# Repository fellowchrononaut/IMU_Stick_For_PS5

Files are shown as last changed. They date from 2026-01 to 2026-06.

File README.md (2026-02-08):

Idea is to create a peripheral for PS5 Access Controller that would allow single joystick control using orientation sensor.

Prototype Circuit :

Note:
There are 2 output TRRS connectors
1. Output directly from Voltage Divider might drop with the 1.8v PS5 Access Controller Vdd load
2. Output from op-amp (LM358P) should theoretically maintain voltage even with the PS5 Access Controller Load (1.8v Vdd)

Limitations:
- Output can only reach a maximum of 1.65v for each channel because I did not have the right combination of resistors for the voltage divider. This means that we lose some range as the controller accepts upto 1.8v.
- Because of the follower circuit of the op-amp, the voltage changes may not be responsive enough.

TODO:

- Test on the PS5 Access controller
- Try voltage divider with 10k+12k resistors instead of the current 10k+10k
- Use the Digipot for smoother control
- Design casing and strap for placement on foot

<p align='center'>
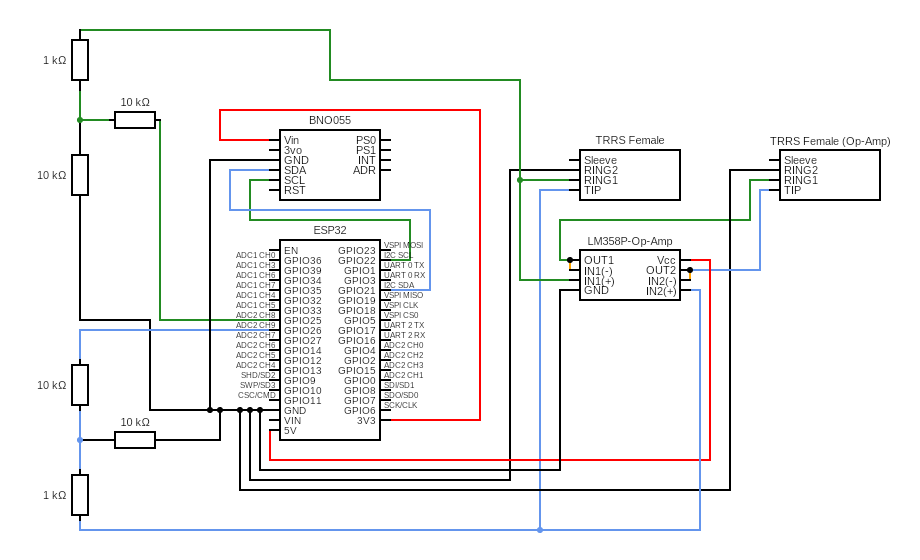
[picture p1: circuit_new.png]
    
</p>

<p align='center'>
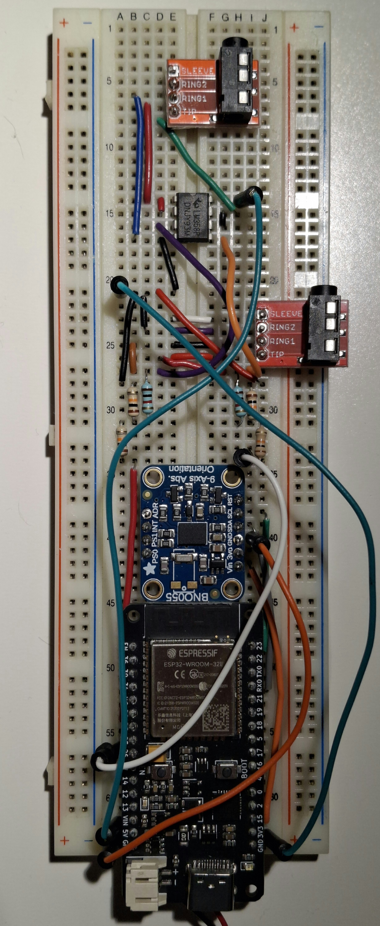
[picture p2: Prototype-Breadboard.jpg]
    
</p>

<p align='center'>
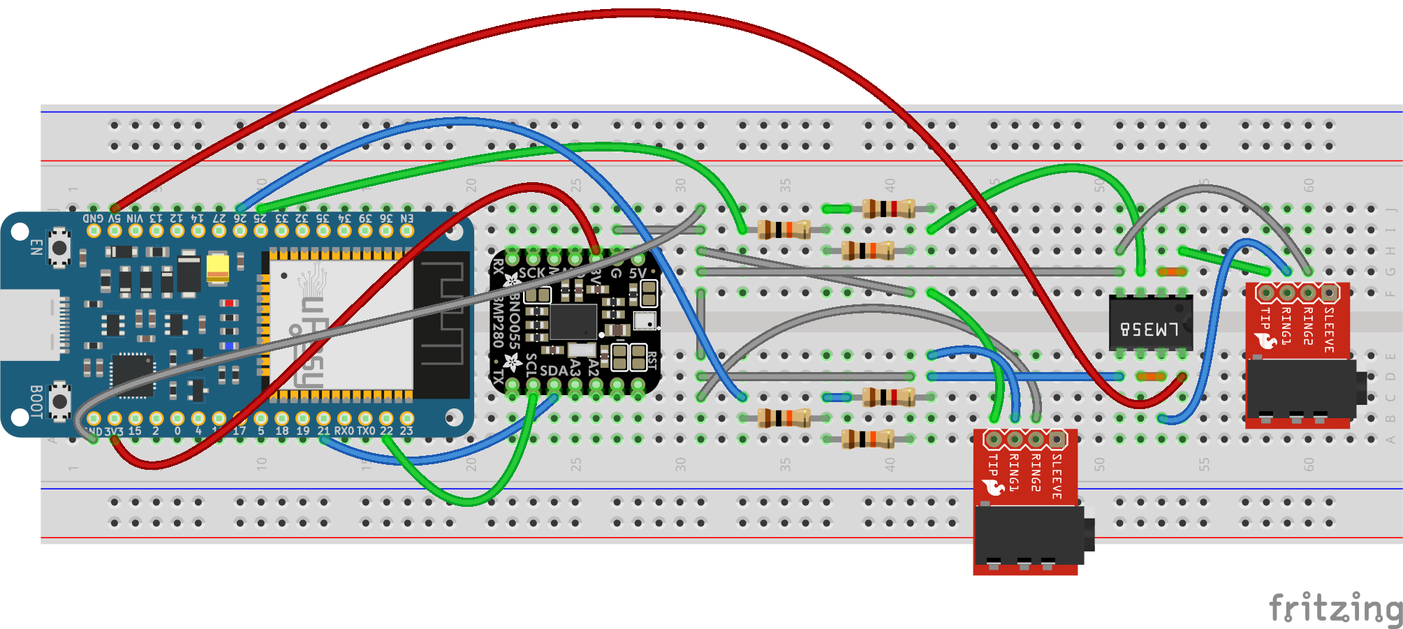
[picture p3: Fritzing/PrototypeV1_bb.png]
    
</p>

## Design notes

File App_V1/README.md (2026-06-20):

# IMU Stick V1 — App + Firmware

Desktop configurator and ESP32 firmware for the foot-mounted IMU → PS5 Access
Controller stick adapter.

- `firmware/imu_stick_v1/` — Arduino sketch for the ESP32 (BNO055 + DAC out)
- `app/imu_stick_app.py` — Tkinter desktop configurator
- `requirements.txt` — Python dependencies

---

## Quick start (desktop side)

Tested on Ubuntu / Python 3.10+. Should work on any Python 3.8+ system with
Tkinter available.

```bash
cd App_V1
python3 -m venv .venv
source .venv/bin/activate
pip install -r requirements.txt
python app/imu_stick_app.py
```

On Windows or macOS, the virtual gamepad panel will be unavailable (evdev is
Linux-only) but everything else works.

---

## Linux system permissions

Two permissions to set up once. Both persist across reboots.

### Serial port access (so the app can read `/dev/ttyUSB0` without sudo)

```bash
sudo usermod -aG dialout $USER
# log out and back in for group membership to take effect
```

### Virtual gamepad access to `/dev/uinput` (only if you want that feature)

```bash
sudo groupadd -f uinput
sudo usermod -aG uinput,input $USER
echo 'KERNEL=="uinput", MODE="0660", GROUP="uinput", OPTIONS+="static_node=uinput"' \
    | sudo tee /etc/udev/rules.d/99-uinput.rules
sudo udevadm control --reload-rules && sudo udevadm trigger
# log out and back in
```

If you skip this step, the "Enable virtual gamepad output" checkbox will fail
with a permission error in the status line — harmless, just disabled.

---

## Firmware setup

Arduino IDE 2.x. Once-per-machine setup:

1. **ESP32 board package**:
   - `File → Preferences → Additional boards manager URLs`:
     `https://raw.githubusercontent.com/espressif/arduino-esp32/gh-pages/package_esp32_index.json`
   - `Tools → Board → Boards Manager…` → install **esp32 by Espressif Systems**.

2. **BNO055 library** (the Bosch one, not Adafruit's):
   - The project lives at the same path used by the V0 sketch:
     `~/Arduino/libraries/BNO055/`. If you don't have it, install Bosch's BNO055
     example sources there. Either copy from a working machine or use Renzo
     Mischianti's port which the V0 sketch is based on.

3. **Verify the I2C address** in `~/Arduino/libraries/BNO055/BNO055.h` is set to
   `BNO055_I2C_ADDR1` (0x28). This is the default; only change if your board is
   jumpered for 0x29.

4. Open `firmware/imu_stick_v1/imu_stick_v1.ino`, select the board (e.g.
   "ESP32 Dev Module"), select the port (`/dev/ttyUSB0` on Linux), and upload.

The very first line on the serial output after upload should be
`READY imu_stick_v1` — that confirms V1 firmware is running.

---

## Workflow

1. Plug ESP32 into the PC via USB.
2. Launch `python app/imu_stick_app.py`. It auto-connects to `/dev/ttyUSB0`.
3. (One-time, per chip) Wave the IMU until the calibration line reads
   `3, 3, 3, 3`, then click **Save chip cal to NVS** under "BNO055 sensor
   calibration". Future boots will skip the cal dance.
4. Hold the foot in the desired neutral pose and click **Set Neutral
   (capture pose)**.
5. Use the X/Y axis dropdowns, "Invert" checkboxes, and Max-angle / Deadzone
   spinboxes to dial in the mapping. Changes apply live so you can watch the
   DAC react in the readout / on the 2D stick / on the 3D pose viz.
6. Click **Save to ESP32 (persist)** to write the current settings to the
   active profile in NVS.
7. Unplug USB, plug into battery + PS5 controller. ESP32 boots and runs with
   the saved profile.

### Profiles

Use the dropdown to switch between saved profiles. "New…" prompts for a name
and saves current settings under it. "Delete" removes the selected profile
(except the active one — switch first, then delete).

Profile names: 1–12 chars, letters / digits / `_` / `-`.

---

## Troubleshooting

| Symptom | Likely cause |
|---|---|
| App opens but nothing populates | Port wrong, or firmware not the V1 build. The boot banner `READY imu_stick_v1` confirms V1 is running. |
| Live values stuck at all zeros | BNO055 not responding on I2C. Re-run `i2c_scanner` from the V0 folder to check. |
| `cal=0,...` and not climbing | BNO055 needs motion through several orientations. Gyro / accel / mag each calibrate via different motions; see Bosch datasheet section on calibration. |
| `DAC X/Y` won't budge | Baseline not yet captured — click **Set Neutral**. |
| Virtual gamepad checkbox shows "Permission denied" | uinput udev rule not yet applied; see Linux permissions section above. |
| 3D viz panel says "matplotlib not installed" | `pip install matplotlib numpy` in your venv. |

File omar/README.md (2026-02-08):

# README

### Objective

To develop a script and the hardware necessary to test the link between a microcontroller and the PS5 expansion ports.

### Parts List

- [Knockoff Waveshare RP2040-Zero](https://fr.aliexpress.com/item/1005007650325892.html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)
- [MCP4251-103E/P 8bit, dual SPI digital potentiometer with volatile memory](https://fr.farnell.com/en-FR/microchip/mcp4251-103e-p/ic-dpot-5-5v-10kr-14-pdip-spi/dp/1578442)
- [3.5mm Male To 3.5 mm Male TRRS Aux Cable](https://fr.aliexpress.com/item/1005009181119614.html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)
- [3.5mm Female Jack to Bare Wire Open End TRRS](https://fr.aliexpress.com/item/1005008510930978.html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)
- [USB-A to USB-C Cable](https://fr.aliexpress.com/item/1005008494569058.html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)
- [Starter Kit For Arduino](https://fr.aliexpress.com/item/1005006480276775.html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)
- [PS5 Access Controller](https://direct.playstation.com/fr-fr/buy-accessories/access-controller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:)
- [PS5](https://direct.playstation.com/fr-fr/buy-consoles/certified-refurbished-playstation5-digital-edition-console)

Total Cost (Excluding PS5 & Controller) : 40 euros

### Useful Resources

- [Waveshare RP2040-Zero Pinout](https://www.waveshare.com/rp2040-zero.htm)
- [How to configure Waveshare RP2040-Zero in Arduino IDE](https://www.waveshare.com/wiki/RP2040-Zero)
- [How to create a joystick input for PS5 access controller](https://www.youtube.com/watch?v=6_bBL7czNOw)
- [Digital potentiometers and Arduino](https://www.youtube.com/watch?v=AqeGskH0usY&t=781s)
- [Waveshare RP2040-Zero Fritzing component](https://forum.fritzing.org/t/part-request-waveshare-rp2040-zero/16705)
- [How to download Fritzing for free](https://gist.github.com/RyanLua/fc2457d87641bb39754278b01a647526)
- [SPI wikipedia overview](https://en.wikipedia.org/wiki/Serial_Peripheral_Interface#See_also)
- Access™ Controller for PlayStation®5 Expansion Port Specifications PDF
- Microchip MCP413X/415X/423X/425X Datasheet PDF

### Wiring

MCP4251 Pin Allocation

| MCP4251 Pin | Label | Connection Point | Description |
| :--- | :--- | :--- | :--- |
| **1** | CS | **GP5 (SPI CS)** | SPI Chip Select |
| **2** | SCK | **GP2 (SPI SCK)** | SPI Clock |
| **3** | SDI | **GP3 (SPI TX)** | SPI Data Input |
| **4** | Vss | **GND** | Common Ground |
| **5** | P1B | **GND** | Pot 1 Low Side (GND) |
| **6** | P1W | **TIP (Y-AXIS) + GP26 (ADC)** | Pot 1 Wiper |
| **7** | P1A | **Sleeve (1.8V Ref)** | Pot 1 High Side |
| **8** | P0A | **Sleeve (1.8V Ref)** | Pot 0 High Side |
| **9** | P0W | **RING 1 (X-AXIS) + GP27 (ADC)** | Pot 0 Wiper |
| **10** | P0B | **GND** | Pot 0 Low Side (GND) |
| **11** | WP | **3.3V** | Write Protect (Disabled) |
| **12** | SHDN | **3.3V** | Shutdown (Disabled) |
| **13** | SDO | N/A | Not Used |
| **14** | Vdd | **3.3V** | Chip Logic Power |

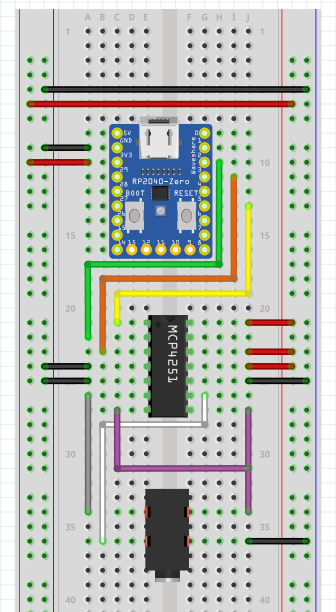
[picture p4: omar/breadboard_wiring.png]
Wiring


### Code Walkthrough

This program allows the user to send X/Y joystick commands to the PS5 Access Controller by modifying the wiper positions of the corresponding potentiometers via the serial port.

```cpp
#include <SPI.h>

const int CS_PIN = 5;
const byte POT_LEFT  = 0x10; // Wiper 1 (Left/Y-axis)
const byte POT_RIGHT = 0x00; // Wiper 0 (Right/X-axis)

const int ADC_LEFT  = 26;    // Monitor for wiper 1 (left/Y-axis)
const int ADC_RIGHT = 27;    // Monitor for wiper 0 (right/X-axis)

void setup() {

  Serial.begin(115200);
  
  // Specify which SPI pins used on RP2040
  SPI.setSCK(2);
  SPI.setTX(3);
  SPI.setRX(4);
  SPI.begin();

  // Set chip select pin to high at the start
  pinMode(CS_PIN, OUTPUT);
  digitalWrite(CS_PIN, HIGH);
  
  // 12 bit ADC on rp2040
  analogReadResolution(12);

  // Blahblah in serial port
  Serial.println("--- Dual-Channel PS5 Controller Tester ---");
  Serial.println("Commands: 'L' or 'R' followed by 0-255 (e.g., L128)");
  Serial.println("Type 'C' to Center both pots.");
  Serial.println("------------------------------------------");
}

void setWiper(byte address, int value) {

  // Failsafe to restrict wiper value commands
  value = constrain(value, 0, 255);

  // Send wiper value to digipot 
  SPI.beginTransaction(SPISettings(1000000, MSBFIRST, SPI_MODE0));
  digitalWrite(CS_PIN, LOW);
  SPI.transfer(address);
  SPI.transfer((byte)value);
  digitalWrite(CS_PIN, HIGH);
  SPI.endTransaction();
}

void displayVoltages() {

  // Read and store measured ADC values as voltages
  float vLeft = (analogRead(ADC_LEFT) * 3.3) / 4095.0;
  float vRight = (analogRead(ADC_RIGHT) * 3.3) / 4095.0;
  
  // Print measured voltages
  Serial.print(">> VOLTAGES | Left (GP26): ");
  Serial.print(vLeft, 3);
  Serial.print("V | Right (GP27): ");
  Serial.print(vRight, 3);
  Serial.println("V");
}

void loop() {

  // If buffer is not emtpy, interpret commands
  if (Serial.available() > 0) {
    char cmd = Serial.read();
    
    // If C/c, center both wipers
    if (cmd == 'C' || cmd == 'c') {
      Serial.println("Centering both sticks...");
      setWiper(POT_LEFT, 128);
      setWiper(POT_RIGHT, 128);
    } 
    else if (cmd == 'L' || cmd == 'l' || cmd == 'R' || cmd == 'r') {
      int val = Serial.parseInt();
      byte addr = (cmd == 'L' || cmd == 'l') ? POT_LEFT : POT_RIGHT;
      setWiper(addr, val);
      Serial.print("Set "); Serial.print(cmd); Serial.print(" to "); Serial.println(val);
    }

    // Clear buffer
    while(Serial.available() > 0) Serial.read(); 
    
    // Show results of the move
    delay(10); // Small delay for ADC stabilization
    displayVoltages();
  }
}
```

### Test Procedure

1. Turn ON PS5 Access Controller
2. Connect 3.5 mm Male jack to PS5 Access Controller expansion port
3. Verify voltage drop between the sleeve and ring 2 is 1.8V
4. Turn OFF PS5 Access Controller
5. Wire 3.5 mm jack to breadboard according to wiring diagram
6. Turn ON microcontroller and PS5 Access Controller
7. Send X/Y joystick commands from Arduino IDE serial port to PS5 Access Controller

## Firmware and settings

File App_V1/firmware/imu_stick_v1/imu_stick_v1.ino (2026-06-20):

/**
 * IMU Stick V1 firmware
 * - BNO055 over I2C (address 0x28, NDOF mode)
 * - Two ESP32 DAC channels driving a PS5 Access Controller stick via op-amp
 * - Configurable axis mapping (source, invert, max angle, deadzone) per channel
 * - Neutral pose calibration
 * - Multiple named profiles persisted in NVS
 * - BNO055 sensor calibration offsets persisted in NVS (skip re-cal on boot)
 *
 * Serial protocol (line-based, 115200 baud):
 *   Host -> ESP32:
 *     STATUS                              dump current config (CFG line)
 *     SET X.src=heading Y.inv=1 ...       update any subset of X/Y fields in RAM
 *     NEUTRAL                             capture current pose as baseline (RAM)
 *     SAVE                                persist current RAM config to active profile
 *     LOAD                                reload active profile from NVS into RAM
 *     RESET                               restore defaults in RAM (Save to persist)
 *     LIST_PROFILES                       reply: PROFILES <comma list>
 *     SELECT_PROFILE <name>               load profile into RAM, set active
 *     SAVE_PROFILE <name>                 save RAM config as <name>, mark active
 *     DELETE_PROFILE <name>               remove named profile
 *     SAVE_BNO_CAL                        snapshot BNO055 cal offsets to NVS
 *     CLEAR_BNO_CAL                       remove saved BNO055 cal
 *   ESP32 -> host:
 *     READY imu_stick_v1                  on boot
 *     CFG ...                             reply to STATUS; includes profile=, bno_cal_saved=
 *     PROFILES <name1,name2,...>          reply to LIST_PROFILES (empty -> "PROFILES")
 *     OK ... / ERR ...                    command replies
 *     D h=.. p=.. r=.. dx=.. dy=.. cal=s,g,a,m baseline_set=0|1
 *                                         streamed at ~10 Hz
 *
 * NVS keys (namespace "imuv1"):
 *   active        active profile name (string, default "default")
 *   prof_list     comma-separated profile names
 *   p_<name>      Config blob (per profile)
 *   bno_cal       22-byte BNO055 calibration offset blob
 */

#include "BNO055_support.h"
#include <Wire.h>
#include <Preferences.h>

#define DAC_X 25                    // Ring 1 on TRRS (stick X)
#define DAC_Y 26                    // Tip on TRRS (stick Y)
#define BNO055_SAMPLERATE_DELAY_MS 100
#define CONFIG_MAGIC 0xC0DE
#define BNO055_I2C_ADDRESS 0x28
#define BNO055_CAL_REG_START 0x55
#define BNO055_CAL_BLOB_SIZE 22
#define PROFILE_NAME_MAX 12

enum AxisSource : uint8_t { SRC_HEADING = 0, SRC_PITCH = 1, SRC_ROLL = 2 };

struct AxisConfig {
  uint8_t src;
  uint8_t invert;
  float max_angle;
  float dead_zone;
};

struct Config {
  AxisConfig x;
  AxisConfig y;
  float baseline_heading;
  float baseline_pitch;
  float baseline_roll;
  uint8_t baseline_set;
  uint16_t magic;
};

Config cfg;
char activeProfile[PROFILE_NAME_MAX + 1] = "default";
bool bnoCalSaved = false;

struct bno055_t myBNO;
struct bno055_euler myEulerData;
unsigned char sysCal = 0, gyroCal = 0, accelCal = 0, magCal = 0;

unsigned long lastSample = 0;
String inputLine;
Preferences prefs;

// ---------------- defaults ----------------
void loadDefaults() {
  cfg.x = { SRC_HEADING, 0, 25.0f, 0.0f };
  cfg.y = { SRC_ROLL,    0, 25.0f, 0.0f };
  cfg.baseline_heading = 0;
  cfg.baseline_pitch = 0;
  cfg.baseline_roll = 0;
  cfg.baseline_set = 0;
  cfg.magic = CONFIG_MAGIC;
}

// ---------------- profile name validation ----------------
bool isValidProfileName(const String& name) {
  if (name.length() == 0 || name.length() > PROFILE_NAME_MAX) return false;
  for (size_t i = 0; i < name.length(); i++) {
    char c = name[i];
    bool ok = (c >= 'a' && c <= 'z') || (c >= 'A' && c <= 'Z') ||
              (c >= '0' && c <= '9') || c == '_' || c == '-';
    if (!ok) return false;
  }
  return true;
}

String profileKey(const char* name) {
  String k = "p_";
  k += name;
  return k;
}

// ---------------- profile list management ----------------
String readProfileList() {
  prefs.begin("imuv1", true);
  String list = prefs.getString("prof_list", "");
  prefs.end();
  return list;
}

void writeProfileList(const String& list) {
  prefs.begin("imuv1", false);
  prefs.putString("prof_list", list);
  prefs.end();
}

bool profileExistsInList(const String& list, const char* name) {
  String needle = name;
  // search for comma-delimited token
  int from = 0;
  while (from <= (int)list.length()) {
    int comma = list.indexOf(',', from);
    String token = (comma < 0) ? list.substring(from) : list.substring(from, comma);
    if (token == needle) return true;
    if (comma < 0) break;
    from = comma + 1;
  }
  return false;
}

String addToList(const String& list, const char* name) {
  if (profileExistsInList(list, name)) return list;
  if (list.length() == 0) return String(name);
  return list + "," + name;
}

String removeFromList(const String& list, const char* name) {
  String out = "";
  int from = 0;
  while (from <= (int)list.length()) {
    int comma = list.indexOf(',', from);
    String token = (comma < 0) ? list.substring(from) : list.substring(from, comma);
    if (token != name && token.length() > 0) {
      if (out.length() > 0) out += ",";
      out += token;
    }
    if (comma < 0) break;
    from = comma + 1;
  }
  return out;
}

// ---------------- profile persistence ----------------
bool loadProfileByName(const char* name) {
  Config tmp;
  prefs.begin("imuv1", true);
  size_t n = prefs.getBytes(profileKey(name).c_str(), &tmp, sizeof(tmp));
  prefs.end();
  if (n != sizeof(tmp) || tmp.magic != CONFIG_MAGIC) return false;
  cfg = tmp;
  return true;
}

void saveProfileByName(const char* name) {
  cfg.magic = CONFIG_MAGIC;
  prefs.begin("imuv1", false);
  prefs.putBytes(profileKey(name).c_str(), &cfg, sizeof(cfg));
  prefs.end();
  String list = readProfileList();
  String updated = addToList(list, name);
  if (updated != list) writeProfileList(updated);
}

void deleteProfileByName(const char* name) {
  prefs.begin("imuv1", false);
  prefs.remove(profileKey(name).c_str());
  prefs.end();
  String list = readProfileList();
  String updated = removeFromList(list, name);
  if (updated != list) writeProfileList(updated);
}

// ---------------- active profile pointer ----------------
void readActiveName(char* out) {
  prefs.begin("imuv1", true);
  String s = prefs.getString("active", "default");
  prefs.end();
  s.toCharArray(out, PROFILE_NAME_MAX + 1);
}

void writeActiveName(const char* name) {
  prefs.begin("imuv1", false);
  prefs.putString("active", name);
  prefs.end();
}

// ---------------- BNO055 raw I2C helpers for cal blob ----------------
bool readBNOCalRegisters(uint8_t* buf) {
  bno055_set_operation_mode(OPERATION_MODE_CONFIG);
  delay(25);
  Wire.beginTransmission(BNO055_I2C_ADDRESS);
  Wire.write(BNO055_CAL_REG_START);
  if (Wire.endTransmission(false) != 0) {
    bno055_set_operation_mode(OPERATION_MODE_NDOF);
    delay(25);
    return false;
  }
  size_t got = Wire.requestFrom((uint8_t)BNO055_I2C_ADDRESS, (size_t)BNO055_CAL_BLOB_SIZE);
  for (size_t i = 0; i < BNO055_CAL_BLOB_SIZE; i++) {
    buf[i] = (i < got && Wire.available()) ? Wire.read() : 0;
  }
  bno055_set_operation_mode(OPERATION_MODE_NDOF);
  delay(25);
  return got == BNO055_CAL_BLOB_SIZE;
}

bool writeBNOCalRegisters(const uint8_t* buf) {
  bno055_set_operation_mode(OPERATION_MODE_CONFIG);
  delay(25);
  Wire.beginTransmission(BNO055_I2C_ADDRESS);
  Wire.write(BNO055_CAL_REG_START);
  for (size_t i = 0; i < BNO055_CAL_BLOB_SIZE; i++) {
    Wire.write(buf[i]);
  }
  bool ok = (Wire.endTransmission() == 0);
  bno055_set_operation_mode(OPERATION_MODE_NDOF);
  delay(25);
  return ok;
}

bool loadBNOCalFromNVS(uint8_t* buf) {
  prefs.begin("imuv1", true);
  size_t n = prefs.getBytes("bno_cal", buf, BNO055_CAL_BLOB_SIZE);
  prefs.end();
  return n == BNO055_CAL_BLOB_SIZE;
}

void saveBNOCalToNVS(const uint8_t* buf) {
  prefs.begin("imuv1", false);
  prefs.putBytes("bno_cal", buf, BNO055_CAL_BLOB_SIZE);
  prefs.end();
}

void clearBNOCalFromNVS() {
  prefs.begin("imuv1", false);
  prefs.remove("bno_cal");
  prefs.end();
}

// ---------------- mapping helpers ----------------
const char* srcName(uint8_t s) {
  if (s == SRC_HEADING) return "heading";
  if (s == SRC_PITCH)   return "pitch";
  if (s == SRC_ROLL)    return "roll";
  return "?";
}

int srcCode(const String& name) {
  if (name == "heading") return SRC_HEADING;
  if (name == "pitch")   return SRC_PITCH;
  if (name == "roll")    return SRC_ROLL;
  return -1;
}

float pickAxisValue(uint8_t src, float h, float p, float r) {
  if (src == SRC_HEADING) return h;
  if (src == SRC_PITCH)   return p;
  return r;
}

float pickBaseline(uint8_t src) {
  if (src == SRC_HEADING) return cfg.baseline_heading;
  if (src == SRC_PITCH)   return cfg.baseline_pitch;
  return cfg.baseline_roll;
}

int computeDAC(const AxisConfig& ax, float h, float p, float r) {
  float cur = pickAxisValue(ax.src, h, p, r);
  float base = pickBaseline(ax.src);
  float delta = cur - base;

  if (ax.src == SRC_HEADING) {
    if (delta > 180.0f)  delta -= 360.0f;
    if (delta < -180.0f) delta += 360.0f;
  }

  if (fabsf(delta) < ax.dead_zone) {
    delta = 0.0f;
  } else if (delta > 0.0f) {
    delta -= ax.dead_zone;
  } else {
    delta += ax.dead_zone;
  }

  if (ax.invert) delta = -delta;

  float maxa = ax.max_angle;
  if (maxa < 1.0f) maxa = 1.0f;
  if (delta >  maxa) delta =  maxa;
  if (delta < -maxa) delta = -maxa;

  float normalized = delta / maxa;
  int dac = (int)((normalized + 1.0f) * 127.5f);
  if (dac < 0)   dac = 0;
  if (dac > 255) dac = 255;
  return dac;
}

// ---------------- replies ----------------
void printStatus() {
  Serial.print(F("CFG"));
  Serial.print(F(" profile=")); Serial.print(activeProfile);
  Serial.print(F(" X.src=")); Serial.print(srcName(cfg.x.src));
  Serial.print(F(" X.inv=")); Serial.print(cfg.x.invert);
  Serial.print(F(" X.max=")); Serial.print(cfg.x.max_angle, 2);
  Serial.print(F(" X.dz="));  Serial.print(cfg.x.dead_zone, 2);
  Serial.print(F(" Y.src=")); Serial.print(srcName(cfg.y.src));
  Serial.print(F(" Y.inv=")); Serial.print(cfg.y.invert);
  Serial.print(F(" Y.max=")); Serial.print(cfg.y.max_angle, 2);
  Serial.print(F(" Y.dz="));  Serial.print(cfg.y.dead_zone, 2);
  Serial.print(F(" baseline="));
  Serial.print(cfg.baseline_heading, 2); Serial.print(',');
  Serial.print(cfg.baseline_pitch, 2);   Serial.print(',');
  Serial.print(cfg.baseline_roll, 2);
  Serial.print(F(" baseline_set=")); Serial.print(cfg.baseline_set);
  Serial.print(F(" bno_cal_saved=")); Serial.println(bnoCalSaved ? 1 : 0);
}

void printProfiles() {
  Serial.print(F("PROFILES "));
  Serial.println(readProfileList());
}

// ---------------- SET parser ----------------
void applyField(AxisConfig& ax, const String& field, const String& val) {
  if (field == "src") {
    int c = srcCode(val);
    if (c >= 0) ax.src = c;
  } else if (field == "inv") {
    ax.invert = (val == "1") ? 1 : 0;
  } else if (field == "max") {
    float v = val.toFloat();
    if (v >= 1.0f && v <= 180.0f) ax.max_angle = v;
  } else if (field == "dz") {
    float v = val.toFloat();
    if (v >= 0.0f && v <= 45.0f) ax.dead_zone = v;
  }
}

void handleSet(const String& args) {
  int start = 0;
  while (start < (int)args.length()) {
    int space = args.indexOf(' ', start);
    if (space < 0) space = args.length();
    String pair = args.substring(start, space);
    int eq = pair.indexOf('=');
    if (eq > 0) {
      String key = pair.substring(0, eq);
      String val = pair.substring(eq + 1);
      if (key.startsWith("X.")) {
        applyField(cfg.x, key.substring(2), val);
      } else if (key.startsWith("Y.")) {
        applyField(cfg.y, key.substring(2), val);
      }
    }
    start = space + 1;
  }
  Serial.println(F("OK SET"));
}

// ---------------- command dispatch ----------------
void handleCommand(String cmd) {
  cmd.trim();
  if (cmd.length() == 0) return;

  if (cmd == "STATUS") {
    printStatus();
  } else if (cmd.startsWith("SET ")) {
    handleSet(cmd.substring(4));
  } else if (cmd == "NEUTRAL") {
    bno055_read_euler_hrp(&myEulerData);
    cfg.baseline_heading = (float)myEulerData.h / 16.0f;
    cfg.baseline_pitch   = (float)myEulerData.p / 16.0f;
    cfg.baseline_roll    = (float)myEulerData.r / 16.0f;
    cfg.baseline_set = 1;
    Serial.print(F("OK NEUTRAL baseline="));
    Serial.print(cfg.baseline_heading, 2); Serial.print(',');
    Serial.print(cfg.baseline_pitch, 2);   Serial.print(',');
    Serial.println(cfg.baseline_roll, 2);
  } else if (cmd == "SAVE") {
    saveProfileByName(activeProfile);
    Serial.print(F("OK SAVED profile=")); Serial.println(activeProfile);
  } else if (cmd == "LOAD") {
    bool ok = loadProfileByName(activeProfile);
    Serial.println(ok ? F("OK LOADED") : F("OK DEFAULTS (no saved profile)"));
  } else if (cmd == "RESET") {
    loadDefaults();
    Serial.println(F("OK RESET (not saved)"));
  } else if (cmd == "LIST_PROFILES") {
    printProfiles();
  } else if (cmd.startsWith("SELECT_PROFILE ")) {
    String name = cmd.substring(15); name.trim();
    if (!isValidProfileName(name)) {
      Serial.println(F("ERR invalid profile name"));
      return;
    }
    if (!loadProfileByName(name.c_str())) {
      Serial.print(F("ERR profile not found: ")); Serial.println(name);
      return;
    }
    name.toCharArray(activeProfile, PROFILE_NAME_MAX + 1);
    writeActiveName(activeProfile);
    Serial.print(F("OK SELECTED ")); Serial.println(activeProfile);
  } else if (cmd.startsWith("SAVE_PROFILE ")) {
    String name = cmd.substring(13); name.trim();
    if (!isValidProfileName(name)) {
      Serial.println(F("ERR invalid profile name"));
      return;
    }
    saveProfileByName(name.c_str());
    name.toCharArray(activeProfile, PROFILE_NAME_MAX + 1);
    writeActiveName(activeProfile);
    Serial.print(F("OK SAVED_PROFILE ")); Serial.println(activeProfile);
  } else if (cmd.startsWith("DELETE_PROFILE ")) {
    String name = cmd.substring(15); name.trim();
    if (!isValidProfileName(name)) {
      Serial.println(F("ERR invalid profile name"));
      return;
    }
    if (name == activeProfile) {
      Serial.println(F("ERR cannot delete active profile"));
      return;
    }
    deleteProfileByName(name.c_str());
    Serial.print(F("OK DELETED ")); Serial.println(name);
  } else if (cmd == "SAVE_BNO_CAL") {
    uint8_t buf[BNO055_CAL_BLOB_SIZE];
    if (!readBNOCalRegisters(buf)) {
      Serial.println(F("ERR could not read BNO cal"));
      return;
    }
    saveBNOCalToNVS(buf);
    bnoCalSaved = true;
    Serial.println(F("OK SAVED_BNO_CAL"));
  } else if (cmd == "CLEAR_BNO_CAL") {
    clearBNOCalFromNVS();
    bnoCalSaved = false;
    Serial.println(F("OK CLEARED_BNO_CAL"));
  } else {
    Serial.print(F("ERR unknown: "));
    Serial.println(cmd);
  }
}

// ---------------- setup ----------------
void setup() {
  Serial.begin(115200);
  delay(100);

  Wire.begin();
  delay(800);                                       // BNO055 power-on settling
  BNO_Init(&myBNO);

  // If a saved BNO cal exists, write it back to the chip before going into NDOF.
  uint8_t calBuf[BNO055_CAL_BLOB_SIZE];
  if (loadBNOCalFromNVS(calBuf)) {
    writeBNOCalRegisters(calBuf);                   // also leaves us in NDOF
    bnoCalSaved = true;
  } else {
    bno055_set_operation_mode(OPERATION_MODE_NDOF);
    delay(30);
    bnoCalSaved = false;
  }

  // Active profile.
  readActiveName(activeProfile);
  if (!loadProfileByName(activeProfile)) {
    loadDefaults();                                 // first-ever boot or wiped NVS
    saveProfileByName(activeProfile);
  }

  dacWrite(DAC_X, 128);
  dacWrite(DAC_Y, 128);

  Serial.println(F("READY imu_stick_v1"));
}

// ---------------- loop ----------------
void loop() {
  while (Serial.available()) {
    char c = (char)Serial.read();
    if (c == '\n') {
      handleCommand(inputLine);
      inputLine = "";
    } else if (c != '\r') {
      inputLine += c;
      if (inputLine.length() > 200) inputLine = "";
    }
  }

  if ((millis() - lastSample) < BNO055_SAMPLERATE_DELAY_MS) return;
  lastSample = millis();

  bno055_read_euler_hrp(&myEulerData);
  float h = (float)myEulerData.h / 16.0f;
  float p = (float)myEulerData.p / 16.0f;
  float r = (float)myEulerData.r / 16.0f;

  int dx = 128, dy = 128;
  if (cfg.baseline_set) {
    dx = computeDAC(cfg.x, h, p, r);
    dy = computeDAC(cfg.y, h, p, r);
    dacWrite(DAC_X, dx);
    dacWrite(DAC_Y, dy);
  }

  bno055_get_syscalib_status(&sysCal);
  bno055_get_gyrocalib_status(&gyroCal);
  bno055_get_accelcalib_status(&accelCal);
  bno055_get_magcalib_status(&magCal);

  Serial.print(F("D h="));  Serial.print(h, 2);
  Serial.print(F(" p="));   Serial.print(p, 2);
  Serial.print(F(" r="));   Serial.print(r, 2);
  Serial.print(F(" dx="));  Serial.print(dx);
  Serial.print(F(" dy="));  Serial.print(dy);
  Serial.print(F(" cal=")); Serial.print(sysCal);
  Serial.print(',');        Serial.print(gyroCal);
  Serial.print(',');        Serial.print(accelCal);
  Serial.print(',');        Serial.print(magCal);
  Serial.print(F(" baseline_set=")); Serial.println(cfg.baseline_set);
}

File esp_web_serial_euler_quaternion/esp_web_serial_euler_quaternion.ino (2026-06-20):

/**
 * Simple example with bosch library for bno055 to work with
 * Adafruit webGL example with euler angles
 * https://adafruit.github.io/Adafruit_WebSerial_3DModelViewer/
 *
 * by Renzo Mischianti <www.mischianti.org>
 *
 * https://mischianti.org/
 */
 
#include "BNO055_support.h"     //Contains the bridge code between the API and Arduino
#include <Wire.h>
 
//The device address is set to BNO055_I2C_ADDR2 in this example. You can change this in the BNO055.h file in the code segment shown below.
// /* bno055 I2C Address */
// #define BNO055_I2C_ADDR1                0x28
// #define BNO055_I2C_ADDR2                0x29
// #define BNO055_I2C_ADDR                 BNO055_I2C_ADDR2
 
//Pin assignments as tested on the Arduino Due.
//Vdd,Vddio : 3.3V
//GND : GND
//SDA/SCL : SDA/SCL
//PSO/PS1 : GND/GND (I2C mode)
 
//This structure contains the details of the BNO055 device that is connected. (Updated after initialization)
struct bno055_t myBNO;
struct bno055_euler myEulerData; //Structure to hold the Euler data
struct bno055_quaternion myQuatData; //Structure to hold the Quaternion data
 
unsigned char accelCalibStatus = 0;     //Variable to hold the calibration status of the Accelerometer
unsigned char magCalibStatus = 0;       //Variable to hold the calibration status of the Magnetometer
unsigned char gyroCalibStatus = 0;      //Variable to hold the calibration status of the Gyroscope
unsigned char sysCalibStatus = 0;       //Variable to hold the calibration status of the System (BNO055's MCU)
 
unsigned long lastTime = 0;
#define DAC_X 25 //Ring 1 on TRRS
#define DAC_Y 26 //Tip on TRRS
float baseline_pitch = 0.0; // Baseline pitch (neutral)
float baseline_roll = 0.0; // Baseline roll (neutral)
float baseline_heading = 0.0; // Baseline heading (neutral)
bool is_calibrated = false;
 
/* Set the delay between fresh samples */
#define BNO055_SAMPLERATE_DELAY_MS (100)
#define MAX_ANGLE 25.0
 
void setup() //This code is executed once
{
  Serial.begin(115200);

  //Initialize I2C communication
  Wire.begin();

  // BNO055 needs ~650 ms after power-on before it accepts commands
  delay(800);

  //Initialization of the BNO055
  BNO_Init(&myBNO); //Assigning the structure to hold information about the device

  //Configuration to NDoF mode
  bno055_set_operation_mode(OPERATION_MODE_NDOF);

  // NDOF mode switch settle time (datasheet: 7-19 ms)
  delay(30);

  dacWrite(DAC_X, 128);
  dacWrite(DAC_Y, 128);
  Serial.println("IMU to DAC Initialized. Keep foot/sensor still for initial calibration...");
}

int mapAngleToDAC(float current, float base, float max_deflection, bool isHeading = false) {
  float delta = current - base;
  if (isHeading) {
    if (delta > 180.0) delta -= 360.0;
    else if (delta < -180.0) delta += 360.0;
  }
  // Clamp delta to max_angle range
  if (delta > max_deflection) delta = max_deflection;
  if (delta < -max_deflection) delta = -max_deflection;
  
  // Map -max_deflection..max_deflection to 0..255
  // Neutral (0 delta) becomes 127/128
  float normalized = (delta / max_deflection); // -1.0 to 1.0
  int dac_val = (int)((normalized + 1.0) * 127.5);
  return dac_val;
}
 
void loop() //This code is looped forever
{
  if ((millis() - lastTime) >= BNO055_SAMPLERATE_DELAY_MS) //To stream at 10Hz without using additional timers
  {
    lastTime = millis();
 
    bno055_read_euler_hrp(&myEulerData);            //Update Euler data into the structure

    float pitch = (float)myEulerData.p / 16.00;
    float roll  = (float)myEulerData.r / 16.00;
    float heading  = (float)myEulerData.h / 16.00;

    if (!is_calibrated && millis() > 2000) {
      baseline_pitch = pitch;
      baseline_roll = roll;
      baseline_heading = heading;
      is_calibrated = true;
      Serial.println("Neutral stance captured!");
    }

    if (is_calibrated) {
      // Bench-verified on this mounting: foot yaw drives BNO heading (Ring 1 on TRRS), foot pitch drives BNO roll (Tip on TRRS).
      // Stick X follows foot yaw, stick Y follows foot pitch.
      int dac_x_val = mapAngleToDAC(heading, baseline_heading, MAX_ANGLE, true);
      int dac_y_val = mapAngleToDAC(roll, baseline_roll, MAX_ANGLE, false);

      // Output to PS5 Access Controller
      dacWrite(DAC_X, dac_x_val);
      dacWrite(DAC_Y, dac_y_val);

      Serial.print("DAC-Attitude: ");
      Serial.print(heading); Serial.print(", ");
      Serial.print(pitch); Serial.print(", ");
      Serial.print(roll);
      Serial.print(" | DAC X: "); Serial.print(dac_x_val);
      Serial.print(" Y: "); Serial.println(dac_y_val);
    }


    bno055_read_quaternion_wxyz(&myQuatData);  // Update quaternion data

 
    /* The WebSerial 3D Model Viewer expects data as heading , pitch, roll */
    Serial.print(F("Orientation: "));
    Serial.print(360-(float(myEulerData.h) / 16.00));
    Serial.print(F(", "));
    Serial.print(360-(float(myEulerData.p) / 16.00));
    Serial.print(F(", "));
    Serial.print(360-(float(myEulerData.r) / 16.00));
    Serial.println(F(""));

    // Quaternion output (sensor gives fixed-point, scale = 1/16384)
    float qw = (float)myQuatData.w / 16384.0f;
    float qx = (float)myQuatData.x / 16384.0f;
    float qy = (float)myQuatData.y / 16384.0f;
    float qz = (float)myQuatData.z / 16384.0f;

    float norm = sqrt(qw*qw + qx*qx + qy*qy + qz*qz);
    if (norm > 0.0f) {
      qw /= norm;
      qx /= norm;
      qy /= norm;
      qz /= norm;
    }

    Serial.print(F("Quaternion: "));
    Serial.print(qw, 6);
    Serial.print(F(", "));
    Serial.print(qx, 6);
    Serial.print(F(", "));
    Serial.print(qy, 6);
    Serial.print(F(", "));
    Serial.print(qz, 6);
    Serial.println();

    // Euler-from-quaternion (ZYX intrinsic: yaw, pitch, roll) in degrees, yaw normalized to 0-360
    float sinp = 2.0f * (qw * qy - qz * qx);
    if (sinp >  1.0f) sinp =  1.0f;
    if (sinp < -1.0f) sinp = -1.0f;
    float yaw_q   = atan2(2.0f * (qw * qz + qx * qy), 1.0f - 2.0f * (qy * qy + qz * qz)) * 180.0f / PI;
    float pitch_q = asin(sinp) * 180.0f / PI;
    float roll_q  = atan2(2.0f * (qw * qx + qy * qz), 1.0f - 2.0f * (qx * qx + qy * qy)) * 180.0f / PI;
    if (yaw_q < 0.0f) yaw_q += 360.0f;

    Serial.print(F("EulerFromQuat: "));
    Serial.print(yaw_q, 2);   Serial.print(F(", "));
    Serial.print(pitch_q, 2); Serial.print(F(", "));
    Serial.println(roll_q, 2);

    bno055_get_accelcalib_status(&accelCalibStatus);
    bno055_get_gyrocalib_status(&gyroCalibStatus);
    bno055_get_syscalib_status(&sysCalibStatus);
    bno055_get_magcalib_status(&magCalibStatus);
 
    Serial.print(F("Calibration: "));
    Serial.print(sysCalibStatus, DEC);
    Serial.print(F(", "));
    Serial.print(gyroCalibStatus, DEC);
    Serial.print(F(", "));
    Serial.print(accelCalibStatus, DEC);
    Serial.print(F(", "));
    Serial.print(magCalibStatus, DEC);
    Serial.println(F(""));
 
 
  }
}

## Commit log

2025-12-27 Add BNO055 sensor integration with Serial output
    This code initializes the BNO055 sensor and streams Euler angles and quaternion data over Serial. It includes calibration status for the accelerometer, gyroscope, and magnetometer.
2025-12-27 Add initial implementation for BNO055 sensor with Euler and Quaternion data output
2025-12-27 Implement main functionality for IMU to gamepad mapping with serial input using ViGEm Bus
2026-01-21 Implement DAC output mapping for pitch and roll with initial calibration
2026-01-24 Refactor yaw handling and adjust maximum angle for DAC output
2026-01-24 Rename yaw to heading for clarity and update corresponding labels in the GUI
2026-01-25 added circuit images
2026-01-25 Update README with prototype circuit information
    Added prototype circuit details and notes about output connectors.
2026-01-25 Update circuit image for improved clarity
2026-01-25 New circuit diagram added
2026-01-25 Add prototype breadboard image
2026-01-25 Add circuit design file
2026-01-26 Add Fritzing files and update README TODOs
    [PrototypeV1.fzz]
2026-01-26 updated readme with current limitations
2026-02-08 Rename Capture d’écran 2026-02-08 122054.png to omar/breadboard_wiring.png
2026-06-20 Added 3D visualization and IMU Calibration persistence option
